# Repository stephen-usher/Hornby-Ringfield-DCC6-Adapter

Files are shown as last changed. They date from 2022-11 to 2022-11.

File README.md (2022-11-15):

# Hornby-Ringfield-DCC6-Adapter
 
 This board is designed to interface a 6 pin DCC decoder with the Hornby ringfield motor found in most models from the mid-1970s until the late 1980s. With the appropriate wires and connectors it can be used as a substitute to the original wiring without the need to solder to any of the original parts of the model.
 
 In addition to the PCB you will need:
 >2x SOD-323 format diodes with at least 100mA throughput (for directional lights)
 >2x 2010 SMD 10 ohm resistors
 >2x 6 way 1.27mm pitch through-hole socket
 >Optional 0603 1uF SMD ceramic capacitor
 >Wires with connectors. The ones to connect to the motor block and unpowered bogie on diesels can be obtained from Peter's Spares. The 2.78mm spade connectors are more difficult to source.
 
 Although this was designed to be used with Hornby locos it will work with others, such as Lima. I've recently used this board to upgrade a Lima 08 shunter, just soldering wires, bridging the resistor pads (as the Lima motor has a higher resistance) and swapping the motor wires as the Lima motor runs in the opposite direction.
 
 The reason that the board has two 10 ohm resistors in parallel is that the Hornby ringfield motor has a resistance of 13 ohms. With the DCC decoder outputting 16V (pulsed) there is a possibility of the motor, if stalled, drawing more than the 1 amp which most 6 pin DCC decoders can handle. The parallel capacitors add an extra 5 ohms (spread between two resistors so as to reduce the current in any one resistor), taking the total to 18 ohms, with a maximum current at 16V less than one amp.
 
 The optional 1uF capacitor helps dampen any voltage spikes from the motor.

 The terminology used for the ends of the loco are based upon diesel locos with "forward" being the No.1 end and the rear the No.2 end. Hornby locos have the motor at the No.2 end. So, "Rail 1" connects to the front, undriven, bogie on a diesel and the loco with a tender driven steam loco and "Track 2" to the motor body.

 The DCC Decoder I use is the Bachmann E-Z Command 90 degree 6 Pin DCC Decoder (Ananlogue Compatible), 36-556RA. I've found that for Hornby motors CV10 (back-EMF cut-off) should be given the value 35 and CV212 (back-EMF strength) set to 128.
  
 Note: I've not yet tested the lighting but the circuit conforms to the specification given in the DCC Wiki.

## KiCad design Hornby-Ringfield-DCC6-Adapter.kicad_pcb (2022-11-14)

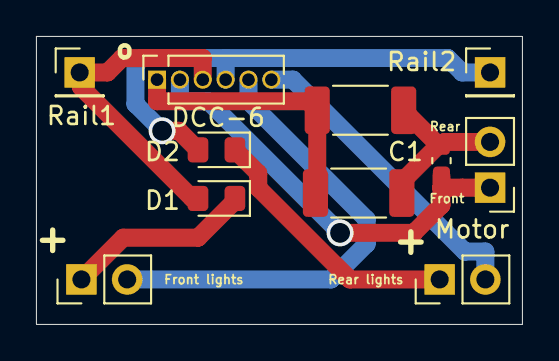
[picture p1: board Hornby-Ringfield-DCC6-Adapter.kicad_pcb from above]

Board: 2 copper layers, 27.0 x 16.0 mm, 11 parts (0 on the bottom side), 9 nets.

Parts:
C1: 1uF; C_0603_1608Metric_Pad1.08x0.95mm_HandSolder
D1, D2: D; D_0805_2012Metric_Pad1.15x1.40mm_HandSolder
DCC-6: Conn_01x06_Female; PinSocket_1x06_P1.27mm_Vertical
Front lights: Conn_01x02_Male; PinHeader_1x02_P2.54mm_Vertical
MOTOR1_R1, MOTOR1_R2: 10; R_2010_5025Metric_Pad1.40x2.65mm_HandSolder
Motor: Conn_01x02_Male; PinHeader_1x02_P2.54mm_Vertical
Rail1, Rail2: Conn_01x01_Male; PinHeader_1x01_P2.54mm_Vertical
Rear lights: Conn_01x02_Male; PinHeader_1x02_P2.54mm_Vertical

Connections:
LED-NEG-1: DCC-6.5, Front lights.2
LED-NEG-2: DCC-6.6, Rear lights.2
LIGHT-PWR1: D1.1, Front lights.1
LIGHT-PWR2: D2.1, Rear lights.1
MOTOR1: DCC-6.1, MOTOR1_R1.1, MOTOR1_R2.1
MOTOR1_OUT: C1.1, MOTOR1_R1.2, MOTOR1_R2.2, Motor.2
MOTOR2: C1.2, DCC-6.2, Motor.1
RAIL1: D1.2, DCC-6.3, Rail1.1
RAIL2: D2.2, DCC-6.4, Rail2.1

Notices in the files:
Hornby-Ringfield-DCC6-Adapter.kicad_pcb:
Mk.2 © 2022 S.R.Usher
